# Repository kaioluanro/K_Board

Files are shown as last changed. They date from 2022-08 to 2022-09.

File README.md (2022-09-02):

# K_Board

Project 65% keyboard RGB custom, based in the QMK Firmware with uma display.

## Note

Project in development

## Features Hardware

- 256 GPIO digitais.
- Rotery Encode Switch.
- Display, Show menu options.

## Licença

[GPL3](https://choosealicense.com/licenses/gpl-3.0/)

## Autores

- [@kaioluanro](https://github.com/kaioluanro)

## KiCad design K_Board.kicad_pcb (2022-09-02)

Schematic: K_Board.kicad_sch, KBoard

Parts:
C1, C2, C3, C4, C10, C15, C16, C17, C18, C19, C20, C21, C22, C23, C24, C25, C26, C27, C28, C29, C30, C31, C32, C33, C34, C35, C36, C37, C38, C39, C40, C41, C42, C43, C44, C45, C46, C47, C48, C49, C50, C51, C52, C53, C54, C55, C56, C57, C58, C59, C60, C61, C62, C63, C64, C65, C66, C67, C68, C69, C70, C71, C72, C73, C74, C75, C76, C77, C78, C79, C80, C81, C82, C83, C84, C85, C86, C87, C88, C89, C90, C91, C102, C103, C104, C105, C106, C107, C108, C109, C110, C111, C112, C113, C114, C115, C116: 100n; C_0402_1005Metric; Manufacturer Part Number 0402F104Z160CT
C5: 10u; CP_EIA-3216-10_Kemet-I_Pad1.58x1.35mm_HandSolder; Manufacturer Part Number TAJA106K016RNJ
C6, C12, C14: 1u; C_0201_0603Metric; Manufacturer Part Number UMK107AB7105KA-T
C7: 10n; C_0402_1005Metric
C8, C9: 8p; C_0402_1005Metric
C11: 4.7u; C_0402_1005Metric
C13, C92, C97: 10u; C_0402_1005Metric; Manufacturer Part Number UMK325AB7106KM-T
C93: 15u; C_0402_1005Metric; Manufacturer Part Number UMK325AB7106KM-T
C94, C95, C99, C100: 1u; C_0805_2012Metric; Manufacturer Part Number CC0805KKX7R7BB105
C96: 2.2u; C_1206_3216Metric
C98: 4.7u; C_1206_3216Metric
C101: 0.1u; C_1206_3216Metric
D1, D7, D13, D19, D24, D29, D34, D40, D45, D50, D55, D61, D67, D70, D71, D83, D85, D86, D87, D88, D89, D90, D91, D92, D93, D94, D95, D96, D97, D98, D99, D100, D101, D102, D103, D104, D105, D106, D107, D108, D109, D110, D111, D112, D113, D114, D115, D116, D117, D118, D119, D120, D121, D122, D123, D124, D125, D126, D127, D128, D129, D130, D131, D132, D133, D134, D135, D136, D137, D138, D139, D140, D141, D162, D163, D164, D165, D166, D167, D168, D169, D170, D171, D172, D173, D174, D175, D176: WS2812B-Mini; LED_SK6812MINI_PLCC4_3.5x3.5mm_P1.75mm; Manufacturer Part Number WS2812B-Mini
D2, D3, D4, D5, D6, D8, D9, D10, D11, D12, D14, D15, D16, D17, D18, D20, D21, D22, D23, D25, D26, D27, D28, D30, D31, D32, D33, D35, D36, D37, D38, D39, D41, D42, D43, D44, D46, D47, D48, D49, D51, D52, D53, D54, D56, D57, D58, D59, D60, D62, D63, D64, D65, D66, D68, D69, D72, D73, D74, D75, D76, D77, D78, D79, D80, D81, D82, D142, D143, D146, D147, D148, D149, D150, D151, D152, D153, D154, D155, D156, D157, D158, D159, D160, D161: 1N4148W; D_SOD-123; Manufacturer Part Number 1N4148W
D84: ZRE B5819W-SL; D_SOD-123; Manufacturer Part Number B5819W-SL
D144, D145: 1N4148W; D_SOD-123
F1: mSMD110-16V; C_1812_4532Metric; Manufacturer Part Number mSMD110-16V
FB1: CBW201209U121T; L_0805_2012Metric; Manufacturer Part Number CBW201209U121T
J1: TYPE-C-31-M-12; USB_C_Receptacle_Hroparts_TYPE-C-31-M-12; Manufacturer Part Number TYPE-C-31-M-12
J2: Conn_01x04; PinHeader_1x4_P2.54mm_Angled
J3: Conns_I2C; SC-74-6_1.5x2.9mm_P0.95mm
J4: Conn_02x18_Counter_Clockwise; SMDIP-18_W7.62mm
J5: USB pins; PinHeader_1x4_P2.54mm_Angled
LED1, LED2, LED3, LED4, LED5, LED6, LED7, LED8, LED9, LED10: LED; LED_THT_2.54mm
Q1: 2N7002; SOT-23; Manufacturer Part Number 2N7002
Q2: AO3401A; SOT-23; Manufacturer Part Number Alpha & Omega Semicon
Q3, Q4: 2N7002; SOT-23
R1, R2: 4.7k; R_0402_1005Metric
R3, R55: 10k; R_0805_2012Metric
R4, R10, R11, R12, R13, R14, R15, R16, R17, R18, R19, R20, R21, R22, R23, R24, R25, R26, R27, R28, R29, R30, R31, R32, R33, R34, R35, R36, R37, R38, R39, R40, R41, R42, R43, R44, R45, R47, R48, R49, R50, R51, R52, R53, R54, R56, R57, R58, R59, R60, R61, R62, R63, R64, R65, R66, R67, R68, R69, R70, R71, R72, R73, R74, R75, R76, R77, R78, R79, R80, R81, R82, R83, R112, R113, R114, R115, R116, R117, R118, R119, R120, R121, R122, R123, R124, R125, R126: 5.1R; R_0805_2012Metric
R5: 0R; R_0402_1005Metric
R6, R7: 100k; R_0805_2012Metric
R8, R9: 5.1k; R_0805_2012Metric
R46: 1.5k; R_0402_1005Metric
R84, R85, R101, R102, R103, R104, R105: 4.7k; R_0805_2012Metric
R86, R87, R89, R90, R93, R94, R96, R97, R98, R99: 1k; R_0805_2012Metric; Manufacturer Part Number 0805W8F1001T5E
R88, R95: 100R; R_0402_1005Metric; Manufacturer Part Number 0402WGF1000TCE
R91, R92: 10k; R_0402_1005Metric; Manufacturer Part Number 0402WGF1002TCE
R100: 530k; R_0805_2012Metric
R106, R108, R110: 100R; R_0402_1005Metric
R107: 330k; R_0402_1005Metric
R109: 1M; R_0402_1005Metric
R111: 10K; R_0402_1005Metric
SW1: EC11E1544407; RotaryEncoder_Alps_EC11E-Switch_Vertical_H20mm; Manufacturer Part Number EC11E1544407
SW2, SW8, SW9, SW10, SW11, SW14, SW15, SW16, SW17, SW19, SW20, SW21, SW22, SW23, SW24, SW25, SW26, SW27, SW28, SW29, SW30, SW31, SW32, SW33, SW34, SW35, SW36, SW37, SW38, SW40, SW41, SW42, SW43, SW44, SW45, SW46, SW47, SW48, SW49, SW50, SW51, SW52, SW53, SW54, SW55, SW56, SW57, SW58, SW59, SW60, SW61, SW62, SW63, SW64, SW65, SW66, SW67, SW68, SW69, SW70, SW71, SW72, SW74, SW76, SW77, SW78, SW79, SW80, SW81, SW82, SW83, SW84: Mechanical_Switch; MX100
SW3: Mechanical_Switch; MX150
SW4, SW75: Mechanical_Switch; MX175
SW5, SW6, SW12, SW18: Mechanical_Switch; MX125
SW7: Mechanical_Switch; MX225
SW13: K2-1187SQ-A4SW-06; Manufacturer Part Number K2-1187SQ-A4SW-06
SW39: Mechanical_Switch; MX625R
SW73, SW85, SW86: Mechanical_Switch; MX200
U1: AT24C256C-SSHL-T; SOIC-8; Manufacturer Part Number AT24C256C-SSHL-T
U2: STM32F411CEU6; STM_UFQFPN-48_LQFP-48-1EP_7x7mm_P0.5mm_HandSoldering_Therma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; Manufacturer Part Number STM32F411
U3: SGM2007-3.3XN5/TR; SOT-23-5; Manufacturer Part Number SGM2007-3.3XN5/TR
U4: TXS0101DCKR; SOT-363_SC-70-6; Manufacturer Part Number TXS0101DCKR
U5, U6: PCF8575; VQFN-24-1EP_4x4mm_P0.5mm_EP2.45x2.45mm_ThermalVias
U7: 0.96'_display_OLED; 0.96 OLED Display
U8: USBLC6-2SC6; SOT-23-6; Manufacturer Part Number USBLC6-2SC6; LCSC Part Number C7519
X1: X6521WR-2x05H-C30D60; PinHeader_2x5_P2.54mm_Vertical_Staggered; Manufacturer Part Number X6521WR-2x05H-C30D60
X2: Conn_01x03; PinHeader_1x3_P2.54mm_Vertical
Y1: X1E0000210621; Crystal_SMD_3225-4Pin_3.2x2.5mm; Manufacturer Part Number 25MHz SMD Crystal Resonator 9pF 40Ω ±10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

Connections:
3V3: C1.2, C2.1, C3.1, C4.2, C5.1, C6.1, C7.1, C10.2, C14.1, C62.1, C94.2, C95.2, D84.2 (A), D144.1 (K), J2.2, J2.3, J2.4, J3.3, J3.4, J3.5, J3.6, R1.1, R2.1, R7.1, R46.1, R55.1, R84.1, R85.1, R101.2, R102.1, R103.1, R104.1, R105.1, SW13.1 (A), U1.8 (VCC), U2.1 (VBAT), U2.9 (VDDA/VREF+), U2.21 (B10), U2.24 (VDD), U2.29 (PA8), U2.36 (VDD), U2.39 (PB3), U2.40 (PB4), U2.48 (VDD), U3.5 (OUT), U4.1 (VCCA), U5.24 (VCC), U6.21 (A0), U6.24 (VCC), U7.5 (VCC), U7.8 (VCC), X1.7, X1.8
5V: C12.1, C63.2, D84.1 (K), F1.2, J5.1, Q2.2 (S), R4.2, R6.1, R10.2, R11.2, R12.2, R13.2, R14.2, R15.2, R16.2, R17.2, R18.2, R19.2, R20.2, R21.2, R22.2, R23.2, R24.2, R25.2, R26.2, R27.2, R28.2, R29.2, R30.2, R31.2, R32.2, R33.2, R34.2, R35.2, R36.2, R37.2, R38.2, R39.2, R40.2, R41.2, R42.2, R43.2, R44.2, R45.2, R47.2, R48.2, R49.2, R50.2, R51.2, R52.2, R53.2, R54.2, R56.2, R57.2, R58.2, R59.2, R60.2, R61.2, R62.2, R63.2, R64.2, R65.2, R66.2, R67.2, R68.2, R69.2, R70.2, R71.2, R72.2, R73.2, R74.2, R75.2, R76.2, R77.2, R78.2, R79.2, R80.2, R81.2, R82.2, R83.2, R92.2, R112.2, R113.2, R114.2, R115.2, R116.2, R117.2, R118.2, R119.2, R120.2, R121.2, R122.2, R123.2, R124.2, R125.2, R126.2, U3.1 (IN), U3.3 (EN), U4.6 (VCCB), X2.1; also elsewhere on the board
BACKLIGHT_3V3: R88.1, U2.16 (PA6)
BOOT0: C92.1, R107.2, R109.1, R111.2, U2.44 (BOOT0), X1.5
C1: SW2.1, SW3.1, SW4.1, SW5.1, SW6.1, SW19.1, U5.4 (P0)
C2: SW8.1, SW9.1, SW10.1, SW11.1, SW12.1, SW24.1, U5.5 (P1)
C3: SW14.1, SW15.1, SW16.1, SW17.1, SW18.1, SW29.1, U5.6 (P2)
C4: SW20.1, SW21.1, SW22.1, SW23.1, SW34.1, U5.7 (P3)
C5: SW25.1, SW26.1, SW27.1, SW28.1, SW40.1, U5.8 (P4)
C6: SW30.1, SW31.1, SW32.1, SW33.1, SW45.1, U5.9 (P5)
C7: SW35.1, SW36.1, SW37.1, SW38.1, SW39.1, SW50.1, U5.10 (P6)
C8: SW41.1, SW42.1, SW43.1, SW44.1, SW55.1, U5.11 (P7)
C9: SW46.1, SW47.1, SW48.1, SW49.1, SW61.1, U5.13 (P10)
C10: SW51.1, SW52.1, SW53.1, SW54.1, SW67.1, U5.14 (P11)
C11: SW56.1, SW57.1, SW58.1, SW59.1, SW60.1, SW70.1, U5.15 (P12)
C12: SW62.1, SW63.1, SW64.1, SW65.1, SW66.1, SW71.1, U5.16 (P13)
C13: SW68.1, SW69.1, SW72.1, SW74.1, SW83.1, SW84.1, U5.17 (P14)
C14: SW7.1, SW73.1, SW75.1, SW76.1, SW85.1, U5.18 (P15)
C15: SW1.S1, SW79.1, SW80.1, U5.19 (P16)
C16: SW77.1, SW78.1, SW81.1, SW82.1, SW86.1, U5.20 (P17)
DATA_BUS +: J1.A6 (D+), J1.B6 (D+), J5.2, U8.6 (I/O1); also elsewhere on the board
DATA_BUS -: J1.A7 (D-), J1.B7 (D-), J5.3, U8.4 (I/O2); also elsewhere on the board
DATA_USB +: R46.2, U2.33 (PA12/USB_FS_DP), U8.1 (I/O1)
DATA_USB -: U2.32 (PA11/USB_FS_DM), U8.3 (I/O2)
EEPROM_SCL: J3.1, R2.2, U1.6 (SCL), U2.42 (PB6/I2C1_SCL)
EEPROM_SDA: J3.2, R1.2, U1.5 (SDA), U2.43 (PB7/I2C1_SDA)
E_PA0-WKUP: J4.1, U2.10 (PA0-WKUP)
E_PA1: J4.2, U2.11 (PA1)
E_PA2: J4.3, U2.12 (PA2)
E_PA3: J4.4, U2.13 (PA3)
E_PA4: J4.5, U2.14 (PA4)
E_PA7: J4.6, U2.17 (PA7)
E_PA10: J4.7, U2.31 (PA10)
E_PA15: J4.8, U2.38 (PA15)
E_PB0: J4.9, U2.18 (PB0)
E_PB1: J4.10, U2.19 (PB1)
E_PB5: J4.11, U2.41 (PB5)
E_PB8: J4.12, U2.45 (PB8)
E_PB9: J4.13, U2.46 (PB9)
E_PB12: J4.14, U2.25 (PB12)
E_PB13: J4.15, U2.26 (PB13/SPI2_SCK)
E_PB14: J4.16, U2.27 (PB14)
E_PB15: J4.17, U2.28 (PB15/SPI2_MOSI)
E_PC13: J4.18, U2.2 (PC13)
E_S2: D143.2 (A), SW1.S2
Encode_A: C60.2, SW1.A, U2.4 (PC15_OSC32OUT)
Encode_B: C61.1, SW1.B, U2.3 (PC14_OSC32IN)
GND: C1.1, C2.2, C3.2, C4.1, C5.2, C6.2, C7.2, C8.2, C9.2, C10.1, C11.1, C12.2, C13.2, C14.2, C15.1, C16.1, C17.1, C18.1, C19.1, C20.1, C21.1, C22.1, C23.1, C24.1, C25.1, C26.1, C27.1, C28.1, C29.1, C30.1, C31.1, C32.1, C33.1, C34.1, C35.1, C36.1, C37.1, C38.1, C39.1, C40.1, C41.1, C42.1, C43.1, C44.1, C45.1, C46.1, C47.1, C48.1, C49.1, C50.1, C51.1, C52.1, C53.1, C54.1, C55.1, C56.1, C57.1, C58.1, C59.1, C60.1, C61.2, C62.2, C63.1, C64.1, C65.1, C66.1, C67.1, C68.1, C69.1, C70.1, C71.1, C72.1, C73.1, C74.1, C75.1, C76.1, C77.1, C78.1, C79.1, C80.1, C81.1, C82.1, C83.1, C84.1, C85.1, C86.1, C87.1, C88.1, C89.1, C90.1, C91.1, C92.2, C93.2, C94.1, C95.1, C96.2, C97.1, C98.2, C101.2, C102.1, C103.1, C104.1, C105.1, C106.1, C107.1, C108.1, C109.1, C110.1, C111.1, C112.1, C113.1, C114.1, C115.1, C116.1, D1.3 (VSS/GND), D7.3 (VSS/GND), D13.3 (VSS/GND), D19.3 (VSS/GND), D24.3 (VSS/GND), D29.3 (VSS/GND), D34.3 (VSS/GND), D40.3 (VSS/GND), D45.3 (VSS/GND), D50.3 (VSS/GND), D55.3 (VSS/GND), D61.3 (VSS/GND), D67.3 (VSS/GND), D70.3 (VSS/GND), D71.3 (VSS/GND), D83.3 (VSS/GND), D85.3 (VSS/GND), D86.3 (VSS/GND), D87.3 (VSS/GND), D88.3 (VSS/GND), D89.3 (VSS/GND), D90.3 (VSS/GND), D91.3 (VSS/GND), D92.3 (VSS/GND), D93.3 (VSS/GND), D94.3 (VSS/GND), D95.3 (VSS/GND), D96.3 (VSS/GND), D97.3 (VSS/GND), D98.3 (VSS/GND), D99.3 (VSS/GND), D100.3 (VSS/GND), D101.3 (VSS/GND), D102.3 (VSS/GND), D103.3 (VSS/GND), D104.3 (VSS/GND), D105.3 (VSS/GND), D106.3 (VSS/GND), D107.3 (VSS/GND), D108.3 (VSS/GND), D109.3 (VSS/GND), D110.3 (VSS/GND), D111.3 (VSS/GND), D112.3 (VSS/GND), D113.3 (VSS/GND), D114.3 (VSS/GND), D115.3 (VSS/GND), D116.3 (VSS/GND), D117.3 (VSS/GND), D118.3 (VSS/GND), D119.3 (VSS/GND), D120.3 (VSS/GND), D121.3 (VSS/GND), D122.3 (VSS/GND), D123.3 (VSS/GND), D124.3 (VSS/GND), D125.3 (VSS/GND), D126.3 (VSS/GND), D127.3 (VSS/GND), D128.3 (VSS/GND), D129.3 (VSS/GND), D130.3 (VSS/GND), D131.3 (VSS/GND), D132.3 (VSS/GND), D133.3 (VSS/GND), D134.3 (VSS/GND), D135.3 (VSS/GND), D136.3 (VSS/GND), D137.3 (VSS/GND), D138.3 (VSS/GND), D139.3 (VSS/GND), D140.3 (VSS/GND), D141.3 (VSS/GND), D162.3 (VSS/GND), D163.3 (VSS/GND), D164.3 (VSS/GND), D165.3 (VSS/GND), D166.3 (VSS/GND), D167.3 (VSS/GND), D168.3 (VSS/GND), D169.3 (VSS/GND), D170.3 (VSS/GND), D171.3 (VSS/GND), D172.3 (VSS/GND), D173.3 (VSS/GND), D174.3 (VSS/GND), D175.3 (VSS/GND), D176.3 (VSS/GND), FB1.2, J1.A1 (GND), J1.B1 (GND), J2.1, J5.4, LED3.K, LED4.K, LED5.K, LED6.K, LED7.K, LED8.K, LED9.K, LED10.K, Q1.2 (S), Q3.2 (S), Q4.2 (S), R3.2, R6.2, R7.2, R8.2, R9.2, R86.2, R87.2, R91.1, R100.2, R109.2, SW1.C, U1.1 (A0), U1.2 (A1), U1.3 (A2), U1.4 (GND), U1.7 (WP), U2.8 (VSSA), U2.23 (VSS), U2.35 (VSS), U2.47 (VSS), U3.2 (GND), U4.2 (GND), U5.2 (A1), U5.3 (A2), U5.12 (GND), U5.21 (A0), U6.2 (A1), U6.3 (A2), U6.12 (GND), U7.7 (VSS), U8.2 (GND), X1.3, X1.4, X1.10, X2.3, Y1.2, Y1.4; also elsewhere on the board
GNDPWR: FB1.1, J1.S1 (SHIELD)
L1: D146.1 (K), D147.1 (K), D148.1 (K), D149.1 (K), D150.1 (K), D151.1 (K), D152.1 (K), D153.1 (K), D154.1 (K), D155.1 (K), D156.1 (K), D157.1 (K), D158.1 (K), D160.1 (K), U6.4 (P0)
L2: D2.1 (K), D8.1 (K), D14.1 (K), D20.1 (K), D25.1 (K), D30.1 (K), D35.1 (K), D41.1 (K), D46.1 (K), D51.1 (K), D56.1 (K), D62.1 (K), D68.1 (K), D73.1 (K), D143.1 (K), D161.1 (K), U6.5 (P1)
L3: D3.1 (K), D9.1 (K), D15.1 (K), D21.1 (K), D26.1 (K), D31.1 (K), D36.1 (K), D42.1 (K), D47.1 (K), D52.1 (K), D57.1 (K), D63.1 (K), D69.1 (K), D77.1 (K), U6.6 (P2)
L4: D4.1 (K), D10.1 (K), D16.1 (K), D22.1 (K), D27.1 (K), D32.1 (K), D37.1 (K), D43.1 (K), D48.1 (K), D53.1 (K), D58.1 (K), D64.1 (K), D74.1 (K), D78.1 (K), D142.1 (K), U6.7 (P3)
L5: D5.1 (K), D11.1 (K), D17.1 (K), D23.1 (K), D28.1 (K), D33.1 (K), D38.1 (K), D44.1 (K), D49.1 (K), D54.1 (K), D59.1 (K), D65.1 (K), D75.1 (K), D79.1 (K), D81.1 (K), D159.1 (K), U6.8 (P4)
L6: D6.1 (K), D12.1 (K), D18.1 (K), D39.1 (K), D60.1 (K), D66.1 (K), D72.1 (K), D76.1 (K), D80.1 (K), D82.1 (K), U6.9 (P5)
NRST: C93.1, R110.2, U2.7 (NRST), X1.9
unnamed: C11.2, U2.22 (VCAP_1)
unnamed: C13.1, U3.4 (BP/FB)
unnamed: C15.2, D1.1 (VDD), R4.1
unnamed: C16.2, D7.1 (VDD), R10.1
unnamed: C17.2, D13.1 (VDD), R11.1
unnamed: C18.2, D19.1 (VDD), R12.1
unnamed: C19.2, D24.1 (VDD), R13.1
unnamed: C20.2, D29.1 (VDD), R14.1
unnamed: C21.2, D34.1 (VDD), R15.1
unnamed: C22.2, D40.1 (VDD), R16.1
unnamed: C23.2, D45.1 (VDD), R17.1
unnamed: C24.2, D50.1 (VDD), R18.1
unnamed: C25.2, D55.1 (VDD), R19.1
unnamed: C26.2, D61.1 (VDD), R20.1
unnamed: C27.2, D67.1 (VDD), R21.1
unnamed: C28.2, D70.1 (VDD), R22.1
unnamed: C29.2, D71.1 (VDD), R23.1
unnamed: C30.2, D83.1 (VDD), R24.1
unnamed: C31.2, D85.1 (VDD), R25.1
unnamed: C32.2, D86.1 (VDD), R26.1
unnamed: C33.2, D87.1 (VDD), R27.1
unnamed: C34.2, D88.1 (VDD), R28.1
unnamed: C35.2, D89.1 (VDD), R29.1
unnamed: C36.2, D90.1 (VDD), R30.1
unnamed: C37.2, D91.1 (VDD), R31.1
unnamed: C38.2, D92.1 (VDD), R32.1
unnamed: C39.2, D93.1 (VDD), R33.1
unnamed: C40.2, D94.1 (VDD), R34.1
unnamed: C41.2, D95.1 (VDD), R35.1
unnamed: C42.2, D96.1 (VDD), R36.1
unnamed: C43.2, D97.1 (VDD), R37.1
unnamed: C44.2, D98.1 (VDD), R38.1
unnamed: C45.2, D99.1 (VDD), R39.1
unnamed: C46.2, D100.1 (VDD), R40.1
unnamed: C47.2, D101.1 (VDD), R41.1
unnamed: C48.2, D102.1 (VDD), R42.1
unnamed: C49.2, D103.1 (VDD), R43.1
unnamed: C50.2, D104.1 (VDD), R44.1
unnamed: C51.2, D105.1 (VDD), R45.1
unnamed: C52.2, D106.1 (VDD), R47.1
unnamed: C53.2, D107.1 (VDD), R48.1
unnamed: C54.2, D108.1 (VDD), R49.1
unnamed: C55.2, D109.1 (VDD), R50.1
unnamed: C56.2, D110.1 (VDD), R51.1
unnamed: C57.2, D111.1 (VDD), R52.1
unnamed: C58.2, D112.1 (VDD), R53.1
unnamed: C59.2, D113.1 (VDD), R54.1
unnamed: C64.2, D114.1 (VDD), R56.1
unnamed: C65.2, D115.1 (VDD), R57.1
unnamed: C66.2, D116.1 (VDD), R58.1
unnamed: C67.2, D117.1 (VDD), R59.1
unnamed: C68.2, D118.1 (VDD), R60.1
unnamed: C69.2, D119.1 (VDD), R61.1
unnamed: C70.2, D120.1 (VDD), R62.1
unnamed: C71.2, D121.1 (VDD), R63.1
unnamed: C72.2, D122.1 (VDD), R64.1
unnamed: C73.2, D123.1 (VDD), R65.1
unnamed: C74.2, D124.1 (VDD), R66.1
unnamed: C75.2, D125.1 (VDD), R67.1
unnamed: C76.2, D126.1 (VDD), R68.1
unnamed: C77.2, D127.1 (VDD), R69.1
unnamed: C78.2, D128.1 (VDD), R70.1
unnamed: C79.2, D129.1 (VDD), R71.1
unnamed: C80.2, D130.1 (VDD), R72.1
unnamed: C81.2, D131.1 (VDD), R73.1
unnamed: C82.2, D132.1 (VDD), R74.1
unnamed: C83.2, D133.1 (VDD), R75.1
unnamed: C84.2, D134.1 (VDD), R76.1
unnamed: C85.2, D135.1 (VDD), R77.1
unnamed: C86.2, D136.1 (VDD), R78.1
unnamed: C87.2, D137.1 (VDD), R79.1
unnamed: C88.2, D138.1 (VDD), R80.1
unnamed: C89.2, D139.1 (VDD), R81.1
unnamed: C90.2, D140.1 (VDD), R82.1
unnamed: C91.2, D141.1 (VDD), R83.1
unnamed: C96.1, U7.13 (VCOMF)
unnamed: C99.1, U7.1 (C2P)
unnamed: C99.2, U7.2 (C2N)
unnamed: C100.1, U7.3 (C1P)
unnamed: C100.2, U7.4 (C1N)
unnamed: C98.1, C101.1, U7.14 (VCC)
unnamed: C102.2, D162.1 (VDD), R112.1
unnamed: C103.2, D163.1 (VDD), R113.1
unnamed: C104.2, D164.1 (VDD), R114.1
unnamed: C105.2, D165.1 (VDD), R115.1
unnamed: C106.2, D166.1 (VDD), R116.1
unnamed: C107.2, D167.1 (VDD), R117.1
unnamed: C108.2, D168.1 (VDD), R118.1
unnamed: C109.2, D169.1 (VDD), R119.1
unnamed: C110.2, D170.1 (VDD), R120.1
unnamed: C111.2, D171.1 (VDD), R121.1
unnamed: C112.2, D172.1 (VDD), R122.1
unnamed: C113.2, D173.1 (VDD), R123.1
unnamed: C114.2, D174.1 (VDD), R124.1
unnamed: C115.2, D175.1 (VDD), R125.1
unnamed: C116.2, D176.1 (VDD), R126.1
unnamed: D1.2 (DOUT), D29.4 (DIN)
unnamed: D1.4 (DIN), D140.2 (DOUT)
unnamed: D2.2 (A), SW2.2
unnamed: D3.2 (A), SW3.2
unnamed: D4.2 (A), SW4.2
unnamed: D5.2 (A), SW5.2
unnamed: D6.2 (A), SW6.2
unnamed: D8.2 (A), SW8.2
unnamed: D9.2 (A), SW9.2
unnamed: D10.2 (A), SW10.2
unnamed: D11.2 (A), SW11.2
unnamed: D12.2 (A), SW12.2
unnamed: D13.2 (DOUT), D40.4 (DIN)
unnamed: D13.4 (DIN), D136.2 (DOUT)
unnamed: D14.2 (A), SW14.2
unnamed: D15.2 (A), SW15.2
unnamed: D16.2 (A), SW16.2
unnamed: D17.2 (A), SW17.2
unnamed: D18.2 (A), SW18.2
unnamed: D19.2 (DOUT), D45.4 (DIN)
unnamed: D20.2 (A), SW20.2
unnamed: D21.2 (A), SW21.2
unnamed: D22.2 (A), SW22.2
unnamed: D23.2 (A), SW23.2
unnamed: D24.2 (DOUT), D50.4 (DIN)
unnamed: D25.2 (A), SW25.2
unnamed: D26.2 (A), SW26.2
unnamed: D27.2 (A), SW27.2
unnamed: D28.2 (A), SW28.2
unnamed: D29.2 (DOUT), D55.4 (DIN)
unnamed: D30.2 (A), SW30.2
unnamed: D31.2 (A), SW31.2
unnamed: D32.2 (A), SW32.2
unnamed: D33.2 (A), SW33.2
unnamed: D34.2 (DOUT), D61.4 (DIN)
unnamed: D7.2 (DOUT), D34.4 (DIN)
unnamed: D35.2 (A), SW35.2
unnamed: D36.2 (A), SW36.2
unnamed: D37.2 (A), SW37.2
unnamed: D38.2 (A), SW38.2
unnamed: D39.2 (A), SW39.2
unnamed: D40.2 (DOUT), D67.4 (DIN)
unnamed: D41.2 (A), SW41.2
unnamed: D42.2 (A), SW42.2
unnamed: D43.2 (A), SW43.2
unnamed: D44.2 (A), SW44.2
unnamed: D45.2 (DOUT), D70.4 (DIN)
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

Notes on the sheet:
BlackLigth
RGB_Encode
*Total the 256 GPIO digital, in one I2C output .
OLED
Grid LEDs
Spooky pin (*)
*Read Address: 67(Decimal) or 43(hexadecimal) *White Address: 66(Decimal) or 42(hexadecimal)
USB
Grid Switch
(*) "Spooky pins": on STM32F4x1, pins A9 and B2 cannot be used for switch matrix: - A9 is meant to be used as a VBUS sensing. It has a undocumented internal pulldown resistor; - B2 is used as BOOT1 during bootup, so it needs an external pulldown for successful bootup
POWER
EXPENDER GPIO
MCU
Encode_Switch
USB ESD
*Read Address: 65(Decimal) or 41(hexadecimal) *Write Address: 64(Decimal) or 40(hexadecimal)
EEPROM
HARD RESET
Controller RGB
RotaryEncode_SW1
(**) PA9 jumper: a solderable jumper used to tie PA9 to VBUS. It is disconnected by default, hence PA9 is left floating

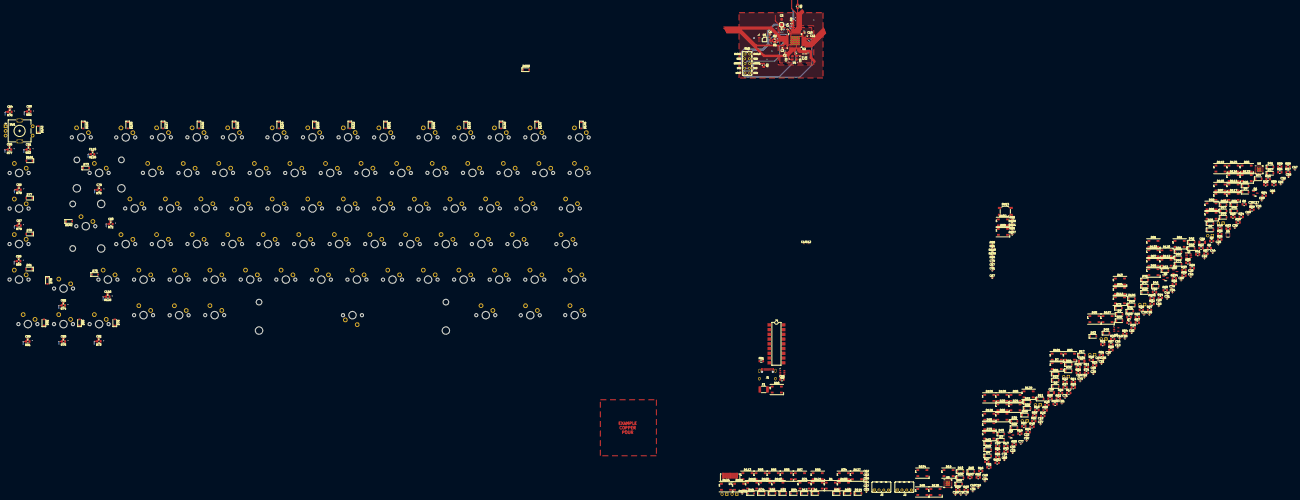
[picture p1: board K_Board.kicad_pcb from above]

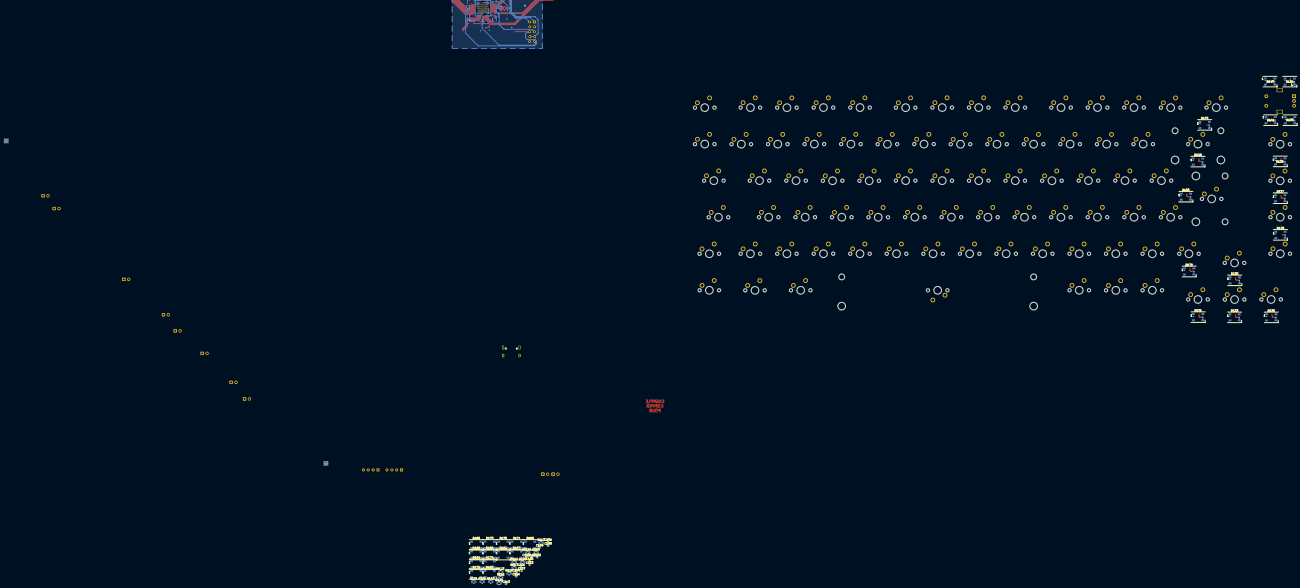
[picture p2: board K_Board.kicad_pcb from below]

Board: 2 copper layers, 535 parts (54 on the bottom side), 362 nets.

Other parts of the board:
F?: mSMD110-16V; C_1812_4532Metric
J?: TYPE-C-31-M-12; USB_C_Receptacle_Hroparts_TYPE-C-31-M-12

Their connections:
5V: F?.2; also elsewhere on the board
DATA_BUS +: J?.A6 (D+), J?.B6 (D+); also elsewhere on the board
DATA_BUS -: J?.A7 (D-), J?.B7 (D-); also elsewhere on the board
GND: J?.A1 (GND), J?.B1 (GND); also elsewhere on the board
unnamed 325: J?.A5 (CC1); also elsewhere on the board
unnamed 326: J?.B5 (CC2); also elsewhere on the board
VBUS: F?.1, J?.A4 (VBUS), J?.B4 (VBUS); also elsewhere on the board

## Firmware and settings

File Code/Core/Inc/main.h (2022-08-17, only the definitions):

#define ENCODE_S_B_Pin GPIO_PIN_14
#define ENCODE_S_B_GPIO_Port GPIOC
#define ENCODE_S_A_Pin GPIO_PIN_15
#define ENCODE_S_A_GPIO_Port GPIOC
#define RGB_LED_TIMCH1_Pin GPIO_PIN_5
#define RGB_LED_TIMCH1_GPIO_Port GPIOA
#define BACKLIGTH_CM_Pin GPIO_PIN_6
#define BACKLIGTH_CM_GPIO_Port GPIOA
#define EXT_GPIO_SCL_Pin GPIO_PIN_10
#define EXT_GPIO_SCL_GPIO_Port GPIOB
#define OLED_SCL_Pin GPIO_PIN_8
#define OLED_SCL_GPIO_Port GPIOA
#define EXT_GPIO_SDA_Pin GPIO_PIN_3
#define EXT_GPIO_SDA_GPIO_Port GPIOB
#define OLED_SDA_Pin GPIO_PIN_4
#define OLED_SDA_GPIO_Port GPIOB
#define EEPROM_SCL_Pin GPIO_PIN_6
#define EEPROM_SCL_GPIO_Port GPIOB
#define EEPROM_SDA_Pin GPIO_PIN_7
#define EEPROM_SDA_GPIO_Port GPIOB

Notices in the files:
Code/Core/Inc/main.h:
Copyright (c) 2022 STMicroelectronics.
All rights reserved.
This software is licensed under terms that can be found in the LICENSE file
